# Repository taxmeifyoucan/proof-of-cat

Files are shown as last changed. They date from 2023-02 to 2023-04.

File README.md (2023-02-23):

# Proof-of-Cat

Proof-of-Cat enables to generate randomness from cats. Check details at https://proofof.cat.

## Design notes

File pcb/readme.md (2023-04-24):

# Catropy PCB

Schematics for the Catropy board. Files in this directory contain all sources for Catropy hardware and can be opened using Eagle or similar software.





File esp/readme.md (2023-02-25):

# Catropy software

For usage and details, check https://proofof.cat/docs

ESP32 is collecting data from gyro and acceloremeter, creates arrays of collected coordinates and calculates how much entropy was collected. When it reaches enough bits, data are served as API.

Right now, everything is implemented using micropython but c++ usage to better utilize ESP features is researched. 

Python [libraries and functions](https://octopusengine.org/download/micropython/stable.tar) are developed together with hardware by [Ocotpus Engine](octopusengine.org).

The webserver used in this project [Nanoweb](https://github.com/hugokernel/micropython-nanoweb).

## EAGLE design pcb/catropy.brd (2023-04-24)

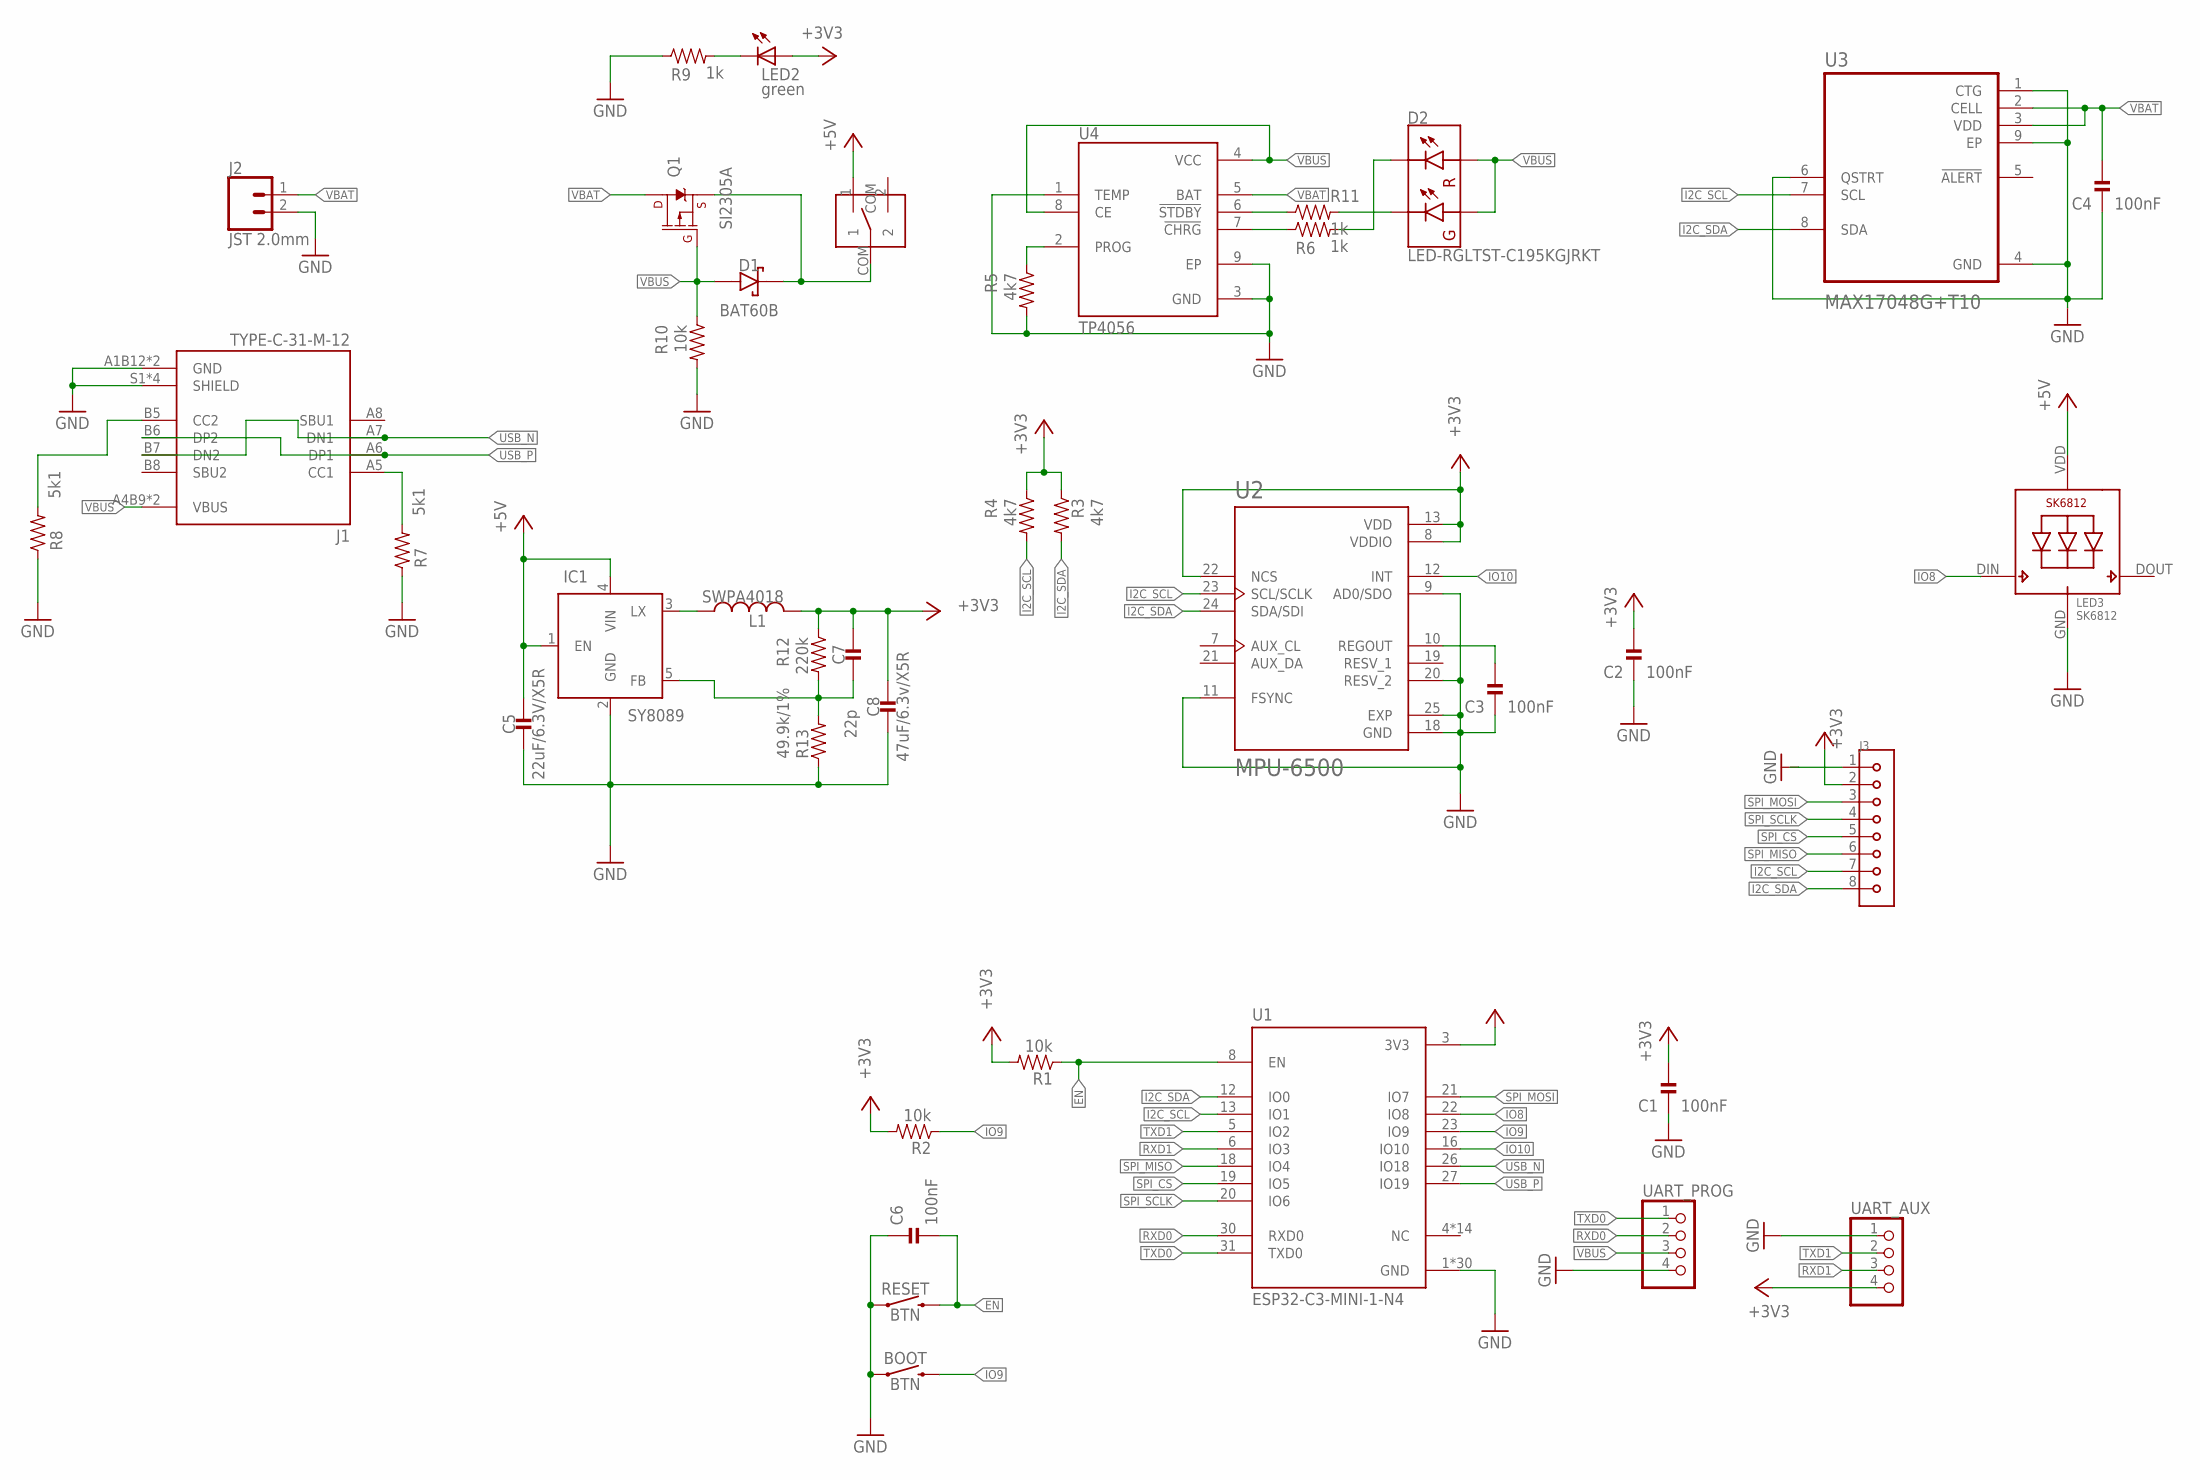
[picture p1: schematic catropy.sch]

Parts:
BOOT: BTN; TACTILE_SWITCH_SMD_6.0X3.5MM; LCSC_PART C118141
C1, C2, C3, C4, C6: 100nF; 0402_CAP
C5: 22uF/6.3V/X5R; 0603_CAP
C7: 22p; 0402_CAP
C8: 47uF/6.3v/X5R; 0805_CAP
D1: BAT60B; SOD323; LCSC_PART C22638
D2: LED-RGLTST-C195KGJRKT; LTST-C195KGJRKT; LCSC_PART C125104
IC1: SY8089; SOT23-5; LCSC_PART C78988
J1: TYPE-C-31-M-12; HRO_TYPE-C-31-M-12; LCSC_PART C165948
J2: JST 2.0mm; JST-2-SMD; LCSC_PART C3029440
J3: SM08B-SRSS-TB(LF)(SN); JST_SM08B-SRSS-TB(LF)(SN); LCSC_PART C160407
L1: SWPA4018; SWPA40XX; LCSC_PART C50543
LED2: green; CHIPLED_0603; LCSC_PART C72043
LED3: SK6812; LED_EC3210R; LCSC_PART C2890041
Q1: SI2305A; SOT23-3; LCSC_PART C347488
R1, R2, R10: 10k; 0402_RES
R3, R4, R5: 4k7; 0402_RES
R6, R9, R11: 1k; 0402_RES
R7, R8: 5k1; 0402_RES
R12: 220k; 0402_RES
R13: 49.9k/1%; 0402_RES; LCSC_PART C208898
RESET: BTN; TACTILE_SWITCH_SMD_6.0X3.5MM; LCSC_PART C118141
U1: ESP32-C3-MINI-1-N4; XCVR_ESP32-C3-MINI-1-N4; LCSC_PART C2838502
U2: MPU-6500; QFN40P300X300X95-25N; LCSC_PART C50278
U3: MAX17048G+T10; SON50P200X200X80-9N; LCSC_PART C2682616
U4: TP4056; SOP127P600X175-9N
U$1: SK12D07VG4; LCSC_PART C393937
UART_AUX: PINHD-1X4; 1X04
UART_PROG: PINHD-1X4; 1X04

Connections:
5V_AUX: D1.P$1 (CATHODE), Q1.2 (S), U$1.COM
+3V3: C1.2, C2.2, C7.1, C8.P$1 (1), J3.2, L1.P$2 (2), LED2.A, R1.2, R2.2, R3.1, R4.1, R12.1, U1.3 (3V3), U2.8 (VDDIO), U2.13 (VDD), U2.22 (NCS), UART_AUX.4
+5V: C5.1, IC1.1 (EN), IC1.4 (VIN), LED3.VDD, U$1.1
EN: C6.2, R1.1, RESET.2, U1.8 (EN)
GND: BOOT.1, C1.1, C2.1, C3.1, C4.1, C5.2, C6.1, C8.P$2 (2), IC1.2 (GND), J1.A1B12 (GND), J1.B1A12 (GND), J1.S1 (SHIELD), J1.S2 (SHIELD), J1.S3 (SHIELD), J1.S4 (SHIELD), J2.2 (1), J3.1, LED3.GND, R5.2, R7.1, R8.1, R9.1, R10.2, R13.1, RESET.1, U1.1 (GND), U1.2 (GND), U1.11 (GND), U1.14 (GND), U1.36 (GND), U1.37 (GND), U1.38 (GND), U1.39 (GND), U1.40 (GND), U1.41 (GND), U1.42 (GND), U1.43 (GND), U1.44 (GND), U1.45 (GND), U1.46 (GND), U1.47 (GND), U1.48 (GND), U1.49_1 (GND), U1.49_2 (GND), U1.49_3 (GND), U1.49_4 (GND), U1.49_5 (GND), U1.49_6 (GND), U1.49_7 (GND), U1.49_8 (GND), U1.49_9 (GND), U1.50 (GND), U1.51 (GND), U1.52 (GND), U1.53 (GND), U2.9 (AD0/SDO), U2.11 (FSYNC), U2.18 (GND), U2.20 (RESV_2), U2.25 (EXP), U3.1 (CTG), U3.4 (GND), U3.6 (QSTRT), U3.9 (EP), U4.1 (TEMP), U4.3 (GND), U4.9 (EP), UART_AUX.1, UART_PROG.4
I2C_SCL: J3.7, R4.2, U1.13 (IO1), U2.23 (SCL/SCLK), U3.7 (SCL)
I2C_SDA: J3.8, R3.2, U1.12 (IO0), U2.24 (SDA/SDI), U3.8 (SDA)
IO8: LED3.DIN (DI), U1.22 (IO8)
IO9: BOOT.2, R2.1, U1.23 (IO9)
IO10: U1.16 (IO10), U2.12 (INT)
unnamed: R5.1, U4.2 (PROG)
unnamed: R6.1, U4.7 (!CHRG)
unnamed: J1.A5 (CC1), R7.2
unnamed: R11.1, U4.6 (!STDBY)
unnamed: D2.P$3 (GC), R11.2
unnamed: C7.2, IC1.5 (FB), R12.2, R13.2
unnamed: C3.2, U2.10 (REGOUT)
unnamed: IC1.3 (LX), L1.P$1 (1)
unnamed: D2.P$4 (RC), R6.2
unnamed: LED2.C, R9.2
unnamed: J1.B5 (CC2), R8.2
RXD0: U1.30 (RXD0), UART_PROG.2
RXD1: U1.6 (IO3), UART_AUX.3
SPI_CS: J3.5, U1.19 (IO5)
SPI_MISO: J3.6, U1.18 (IO4)
SPI_MOSI: J3.3, U1.21 (IO7)
SPI_SCLK: J3.4, U1.20 (IO6)
TXD0: U1.31 (TXD0), UART_PROG.1
TXD1: U1.5 (IO2), UART_AUX.2
USB_N: J1.A7 (DN1), J1.B7 (DN2), U1.26 (IO18)
USB_P: J1.A6 (DP1), J1.B6 (DP2), U1.27 (IO19)
VBAT: C4.2, J2.1 (2), Q1.3 (D), U3.2 (CELL), U3.3 (VDD), U4.5 (BAT)
VBUS: D1.P$2 (ANODE), D2.P$1 (GA), D2.P$2 (RA), J1.A4B9 (VBUS), J1.B4A9 (VBUS), Q1.1 (G), R10.1, U4.4 (VCC), U4.8 (CE), UART_PROG.3

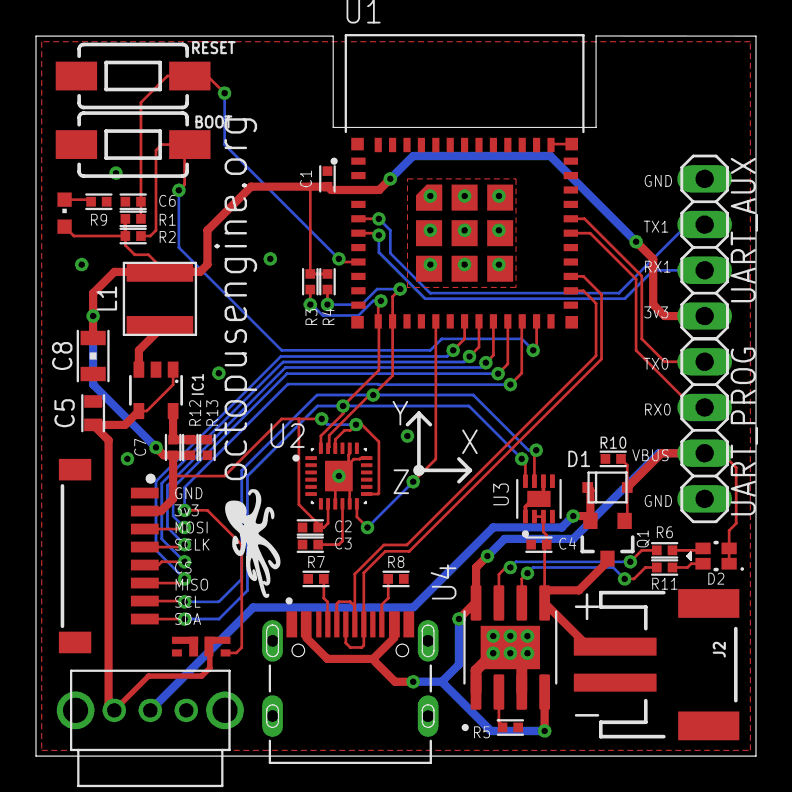
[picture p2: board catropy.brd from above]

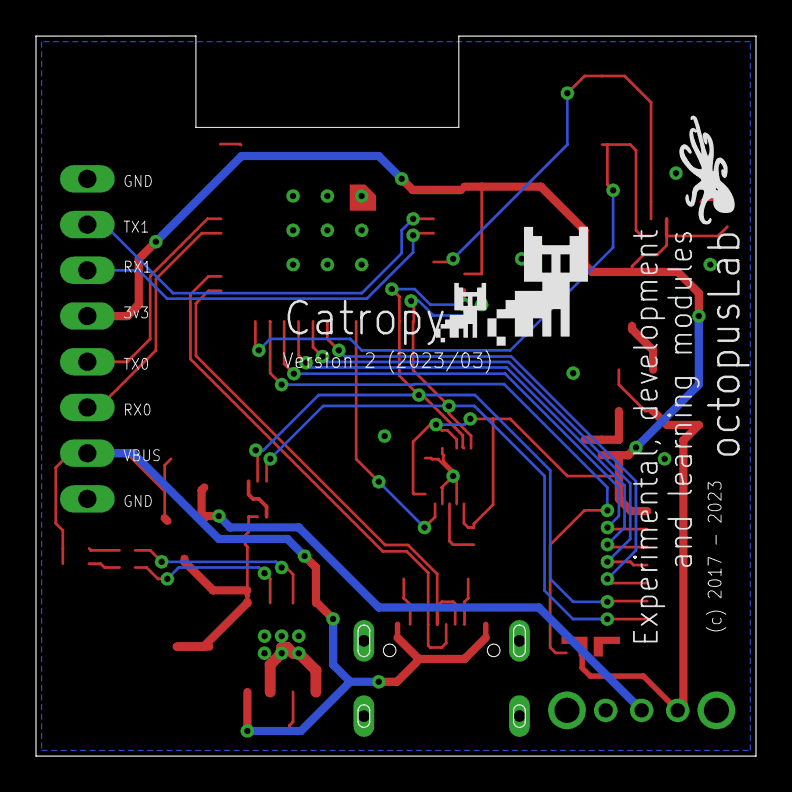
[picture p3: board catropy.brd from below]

Board: 2 copper layers, 40.0 x 40.0 mm, 44 parts (2 on the bottom side), 33 nets.

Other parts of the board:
U$2: OCTOPUSLAB
U$3: OCTOPUSENGINE
U$4: CATROPY_20
U$5: CATROPY_10

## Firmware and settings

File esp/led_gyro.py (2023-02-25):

# upip.install("micropython-mpu9250")

from time import sleep, sleep_ms, ticks_ms
from machine import Pin, I2C
from mpu6500 import MPU6500
from neopixel import NeoPixel


class StatusLed(NeoPixel):
    _last_state = (0,0,0)

    def show_led(self, color, force=False):
        if self._last_state == color and not force:
            return

        self.fill(color)
        self.write()
        self._last_state = color
        print("Write new color")

print ('ws init')
led = StatusLed(Pin(8), 1)
led.show_led((20,0,0))
sleep_ms(250)

print("i2c init")
i2c = I2C(0, sda=Pin(0), scl=Pin(1))
mpu = MPU6500(i2c)
led.show_led((20,0,20))
sleep_ms(250)

print("start")
led.show_led((0,20,0))

while True:
   gyro = mpu.gyro
   accel = mpu.acceleration
   print(gyro[0],gyro[1],gyro[2], accel[0], accel[1], accel[2])
   if accel[2] < 0:
       led.show_led((20,0,0))
   else:
       led.show_led((0,0,20))
   sleep_ms(50)

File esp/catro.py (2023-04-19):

from utime import sleep, sleep_ms, ticks_ms
import utime as time
from sys import exit
import json
import random
import network
import uasyncio
import ubinascii
from wifi_connect import WiFiConnect
from web_server import Nanoweb
from entropy_lib import MAX_SIZE, TARGET_ENTROPY, add_entropy, measure_entropy
from components import init_rgb_led, init_gyro, get_data



DEBUG = False
LED_INTENSITY = 128

print(f"MAX_SIZE: {MAX_SIZE}")
print(f"TARGET_ENTROPY: {TARGET_ENTROPY}")
print("-"*30)

print("Starting Catropy")


led = init_rgb_led()

for i in range(10):
    led.show_led((LED_INTENSITY,0,0))
    sleep_ms(100)
    led.show_led((0,LED_INTENSITY,0))
    sleep_ms(100)

mpu = init_gyro()
naw = Nanoweb()
wlan = network.WLAN(network.STA_IF)


def connect_wifi():
    if not wlan.isconnected():
        print("Connecting wifi")
        try:
            led.show_led((LED_INTENSITY,LED_INTENSITY,0))
            net = WiFiConnect(retries=100)
            wc = net.connect()

            ip_addr = net.ifconfig()[0]
            if ip_addr == "0.0.0.0":
                led.show_led((LED_INTENSITY,0,0))
                print("The wifi doesn't seem not be connected corretly, please check your settings and run the program again.")
            else:
                print("IP address:",ip_addr)
                led.show_led((0,LED_INTENSITY,0))
        except:
            print("The wifi did not connect, please check your settings and run the program again.")
            led.show_led((LED_INTENSITY,0,0))
     
connect_wifi()
if not wlan.isconnected():
    exit()


#deactivate to save battery
#wlan.active(False)

def get_uptime():
    uptime_s = int(time.ticks_ms() / 1000)
    uptime_h = int(uptime_s / 3600)
    uptime_m = int(uptime_s / 60)
    uptime_m = uptime_m % 60
    uptime_s = uptime_s % 60
    return ('{:02d}h {:02d}m {:02d}z'.format(uptime_h, uptime_m, uptime_s))


def rng():
    global entropy_str
    led.show_led((0,LED_INTENSITY,0))
    i=0
    if not "entropy_str" in globals():
        entropy_str = ""
        while True:
            sample_period = int(random.uniform(500, 1100)) 
            sleep_ms(sample_period)
            data = get_data(mpu)
            entropy_str = add_entropy(mpu, entropy_str, data)
            i+=1
            if i % 5 == 0:
                print("Current entropy: {} bits".format(measure_entropy(entropy_str)))
                print("Current lenght:", len(entropy_str))
            if len(entropy_str) > MAX_SIZE and measure_entropy(entropy_str) > TARGET_ENTROPY:
                break
    else:
        for i in range(4):
            sample_period = int(random.uniform(100, 400))
            sleep_ms(sample_period)
            data = get_data(mpu)
            entropy_str = add_entropy(mpu, entropy_str, data)
        print("Current entropy: {} bits".format(measure_entropy(entropy_str)))
        print("Current lenght:", len(entropy_str))
    led.show_led((0,0,LED_INTENSITY))
    return entropy_str

print("Starting randomness generation")
rng()
print("Initial entropy gathered, starting API")

@naw.route("/status")
async def status(request):
    await request.write("HTTP/1.1 200 OK\r\n")
    await request.write("Content-Type: application/json\r\n\r\n")
    uptime_str = get_uptime()
    shannon=measure_entropy(entropy_str)
    bits = len(entropy_str) * 4
    await request.write(json.dumps({
        "uptime": uptime_str,
        "Shannon entropy": shannon,
        "lenght": bits}))

@naw.route("/")
def entropy(request):
    await request.write("HTTP/1.1 200 OK\r\n")
    await request.write("Content-Type: application/json\r\n\r\n")
    random = ubinascii.b2a_base64(rng())[:-2]
    await request.write(json.dumps({
        "": random}))
    
loop = uasyncio.get_event_loop()
if DEBUG:
    print("Starting webserver")

loop.create_task(naw.run())
connect_wifi()
if not wlan.isconnected():
    exit()
led.show_led((0,0,LED_INTENSITY))
loop.run_forever()

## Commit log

2023-02-24 refactoring: and new gyro lib
2023-02-24 add RGB led, refactoring entropy lib, clean up
2023-02-25 Handling LEDs
2023-02-25 Wifi error handling, remove old lib
    [catro.py]
2023-02-25 Add led gyro test
2023-04-18 FIX root entropy endpoint return correct headers
    [catro.py]
2023-04-18 FIX: strip \n from payload in entrypy base64 encoded string
    [catro.py]
2023-04-18 Prolong wifi retries, add yellow RGB led for connecting status
2023-04-24 Sync version v2r2 of PCB
    [catropy.brd, catropy.sch]
2023-04-24 PCB: Added BOM and CPL for power switch
    [catropy_bom_add_switch.csv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]
2023-04-24 PCB: Some TODO

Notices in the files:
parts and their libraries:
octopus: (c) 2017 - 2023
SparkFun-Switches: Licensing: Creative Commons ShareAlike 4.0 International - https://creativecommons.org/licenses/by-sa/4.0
